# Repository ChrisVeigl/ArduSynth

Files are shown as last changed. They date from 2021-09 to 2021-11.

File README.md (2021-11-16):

# ArduSynth
HW/SW for low-cost Arduino-based audio synthesizers, using the Mozzi Library.
Currently, two designs are available: one for the Arduino Nano and one for the TeensyLC microcontroller. The TeensyLC version is recommended and will be updated in the future - it offers more features like Midi control via the Teensy's usbMidi functions.
The KICad projects (Schematics, PCB) are available in the respective HW folders, partnumbers @ digikey / Aliexpress are provided.

## About the demo Synth Sketches

Synthesizer sketches can be added / modified on demand. Currently there are two demo synth designs available, based upon:

* the "K'iin" Synthesizer by Taylan Cihan, see: http://digital.music.cornell.edu/taylancihan/kiin.html
 
* the "Thankyou Drone Synth" by Daniel Sinderson, see:
   https://create.arduino.cc/projecthub/scraptured/phasemod-drone-synth-w-arduino-nano-mozzi-7ab2ff 

## SW-Build instructions and Dependencies

* for compiling the software, the Mozzi-Library must be installed / copied to the Arduino libraries folder, see:
https://github.com/sensorium/Mozzi 

For the TeensyLC version, follwing alternative/additional libraries are used:
* currently this branch of the Mozzi library is needed for TeensyLC support: https://github.com/tomcombriat/Mozzi/tree/Teensy4X
* the Adafruit library for the SSD1306 OLed-Display is used: https://github.com/adafruit/Adafruit_SSD1306 
Please note that a modified version of this library is delivered in the src folder - the display method was adapted in order to call audioHook() - which prevents distorted audio during display updates.
* furthermore, the Adafruit GFX library https://github.com/adafruit/Adafruit-GFX-Library and the Adafruit BUI-IO library https://github.com/adafruit/Adafruit_BusIO are needed - they can be installed from the Arduinos Library manager.
* in order to use the correct I2C interface of the TeensyLC, the Wire1 interface must be enabled either by adding "-DWIRE_IMPLEMENT_WIRE1" to the teensyLC.build.flags.defs in the file Arduino\hardware\teensy\avr\boards.txt file or by uncommenting line 43 in file Arduino\hardware\teensy\avr\libraries\Wire\WireKinetis.h

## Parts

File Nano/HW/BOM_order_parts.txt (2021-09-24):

Arduino Nano: https://de.aliexpress.com/item/32824272738.html
Potentiomenter + Knobs: https://de.aliexpress.com/item/1005001346661310.html

other parts:
https://www.digikey.at/product-detail/de/w%C3%BCrth-elektronik/430476085716/430476085716-ND/5209048
https://www.digikey.at/product-detail/de/creeled-inc/C503B-BCS-CV0Z0461/C503B-BCS-CV0Z0461-ND/1922944
https://www.digikey.at/product-detail/de/stackpole-electronics-inc/CF14JT470R/CF14JT470RCT-ND/1830342
https://www.digikey.at/product-detail/de/harwin-inc/M20-9990345/952-2263-ND/3728227
https://www.digikey.at/product-detail/de/sullins-connector-solutions/NPC02SXON-RC/S9341-ND/2618266
https://www.digikey.at/product-detail/de/adam-tech/EB147A-02-D/2057-EB147A-02-D-ND/9830728
https://at.rs-online.com/web/p/klinken-steckerbuchsen/8051655

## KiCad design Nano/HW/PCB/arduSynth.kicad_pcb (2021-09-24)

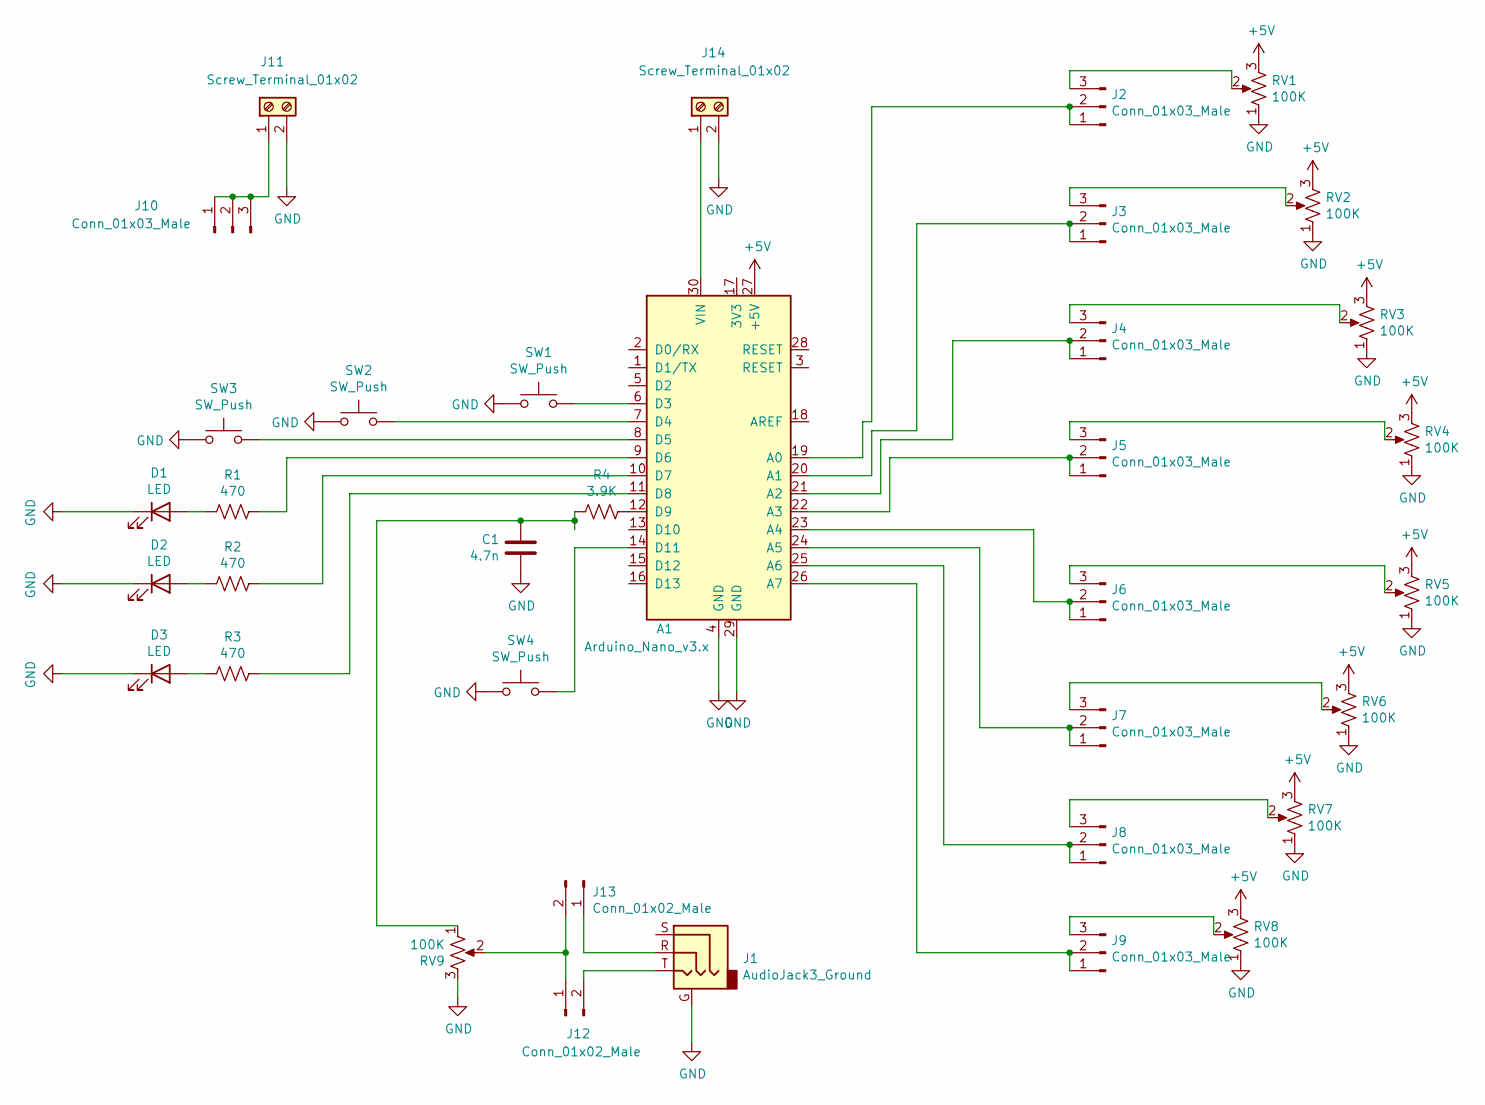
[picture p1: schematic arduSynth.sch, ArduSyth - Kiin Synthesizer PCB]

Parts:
A1: Arduino_Nano_v3.x; Arduino_Nano
C1: 4.7n; C_Rect_L4.6mm_W2.0mm_P2.50mm_MKS02_FKP02
D1, D2, D3: LED; LED_D5.0mm
J1: AudioJack3_Ground; FC68125
J2, J3, J4, J5, J6, J7, J8, J9, J10: Conn_01x03_Male; PinHeader_1x03_P2.54mm_Vertical
J11, J14: Screw_Terminal_01x02; TerminalBlock_bornier-2_P5.08mm
J12, J13: Conn_01x02_Male; PinHeader_1x02_P2.54mm_Vertical
R1, R2, R3: 470; R_Axial_DIN0204_L3.6mm_D1.6mm_P2.54mm_Vertical
R4: 3.9K; R_Axial_DIN0204_L3.6mm_D1.6mm_P2.54mm_Vertical
RV1, RV2, RV3, RV4, RV5, RV6, RV7, RV8, RV9: 100K; Potentiometer_Alps_RK09K_Single_Vertical_modified
SW1, SW2, SW3, SW4: SW_Push; SW_PUSH-12mm_Wuerth-430476085716

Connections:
+5V: A1.27 (+5V), RV1.3, RV2.3, RV3.3, RV4.3, RV5.3, RV6.3, RV7.3, RV8.3
GND: A1.4 (GND), A1.29 (GND), C1.2, D1.1 (K), D2.1 (K), D3.1 (K), J1.G, J11.2, J14.2, RV1.1, RV2.1, RV3.1, RV4.1, RV5.1, RV6.1, RV7.1, RV8.1, RV9.3, SW1.1, SW2.1, SW3.1, SW4.1
unnamed: A1.6 (D3), SW1.2
unnamed: A1.7 (D4), SW2.2
unnamed: A1.8 (D5), SW3.2
unnamed: A1.9 (D6), R1.2
unnamed: A1.10 (D7), R2.2
unnamed: A1.11 (D8), R3.2
unnamed: A1.12 (D9), R4.2
unnamed: A1.14 (D11), SW4.2
unnamed: A1.19 (A0), J2.1, J2.2
unnamed: A1.20 (A1), J3.1, J3.2
unnamed: A1.21 (A2), J4.1, J4.2
unnamed: A1.22 (A3), J5.1, J5.2
unnamed: A1.23 (A4), J6.1, J6.2
unnamed: A1.24 (A5), J7.1, J7.2
unnamed: A1.25 (A6), J8.1, J8.2
unnamed: A1.26 (A7), J9.1, J9.2
unnamed: A1.30 (VIN), J14.1
unnamed: C1.1, R4.1, RV9.1
unnamed: D1.2 (A), R1.1
unnamed: D2.2 (A), R2.1
unnamed: D3.2 (A), R3.1
unnamed: J1.R, J13.1
unnamed: J1.T, J12.2
unnamed: J2.3, RV1.2
unnamed: J3.3, RV2.2
unnamed: J4.3, RV3.2
unnamed: J5.3, RV4.2
unnamed: J6.3, RV5.2
unnamed: J7.3, RV6.2
unnamed: J8.3, RV7.2
unnamed: J9.3, RV8.2
unnamed: J10.1, J10.2, J10.3, J11.1
unnamed: J12.1, J13.2, RV9.2

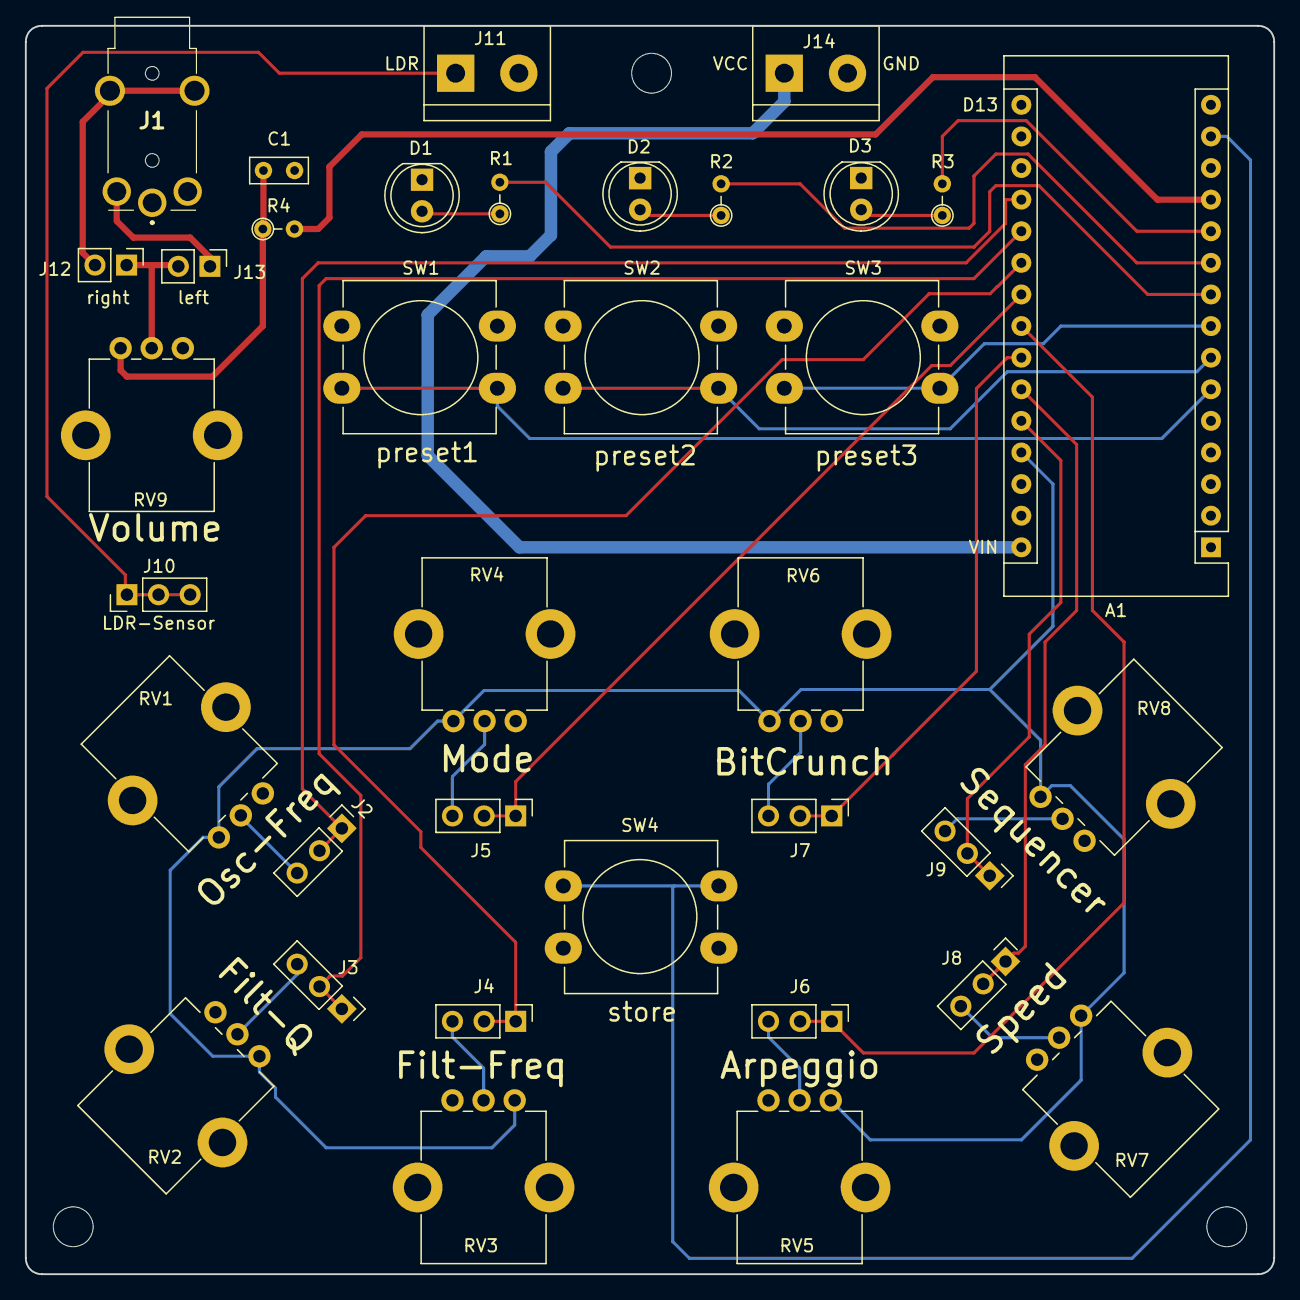
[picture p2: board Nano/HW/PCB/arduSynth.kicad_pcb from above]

Board: 2 copper layers, 100.3 x 100.3 mm, 36 parts (0 on the bottom side), 35 nets.

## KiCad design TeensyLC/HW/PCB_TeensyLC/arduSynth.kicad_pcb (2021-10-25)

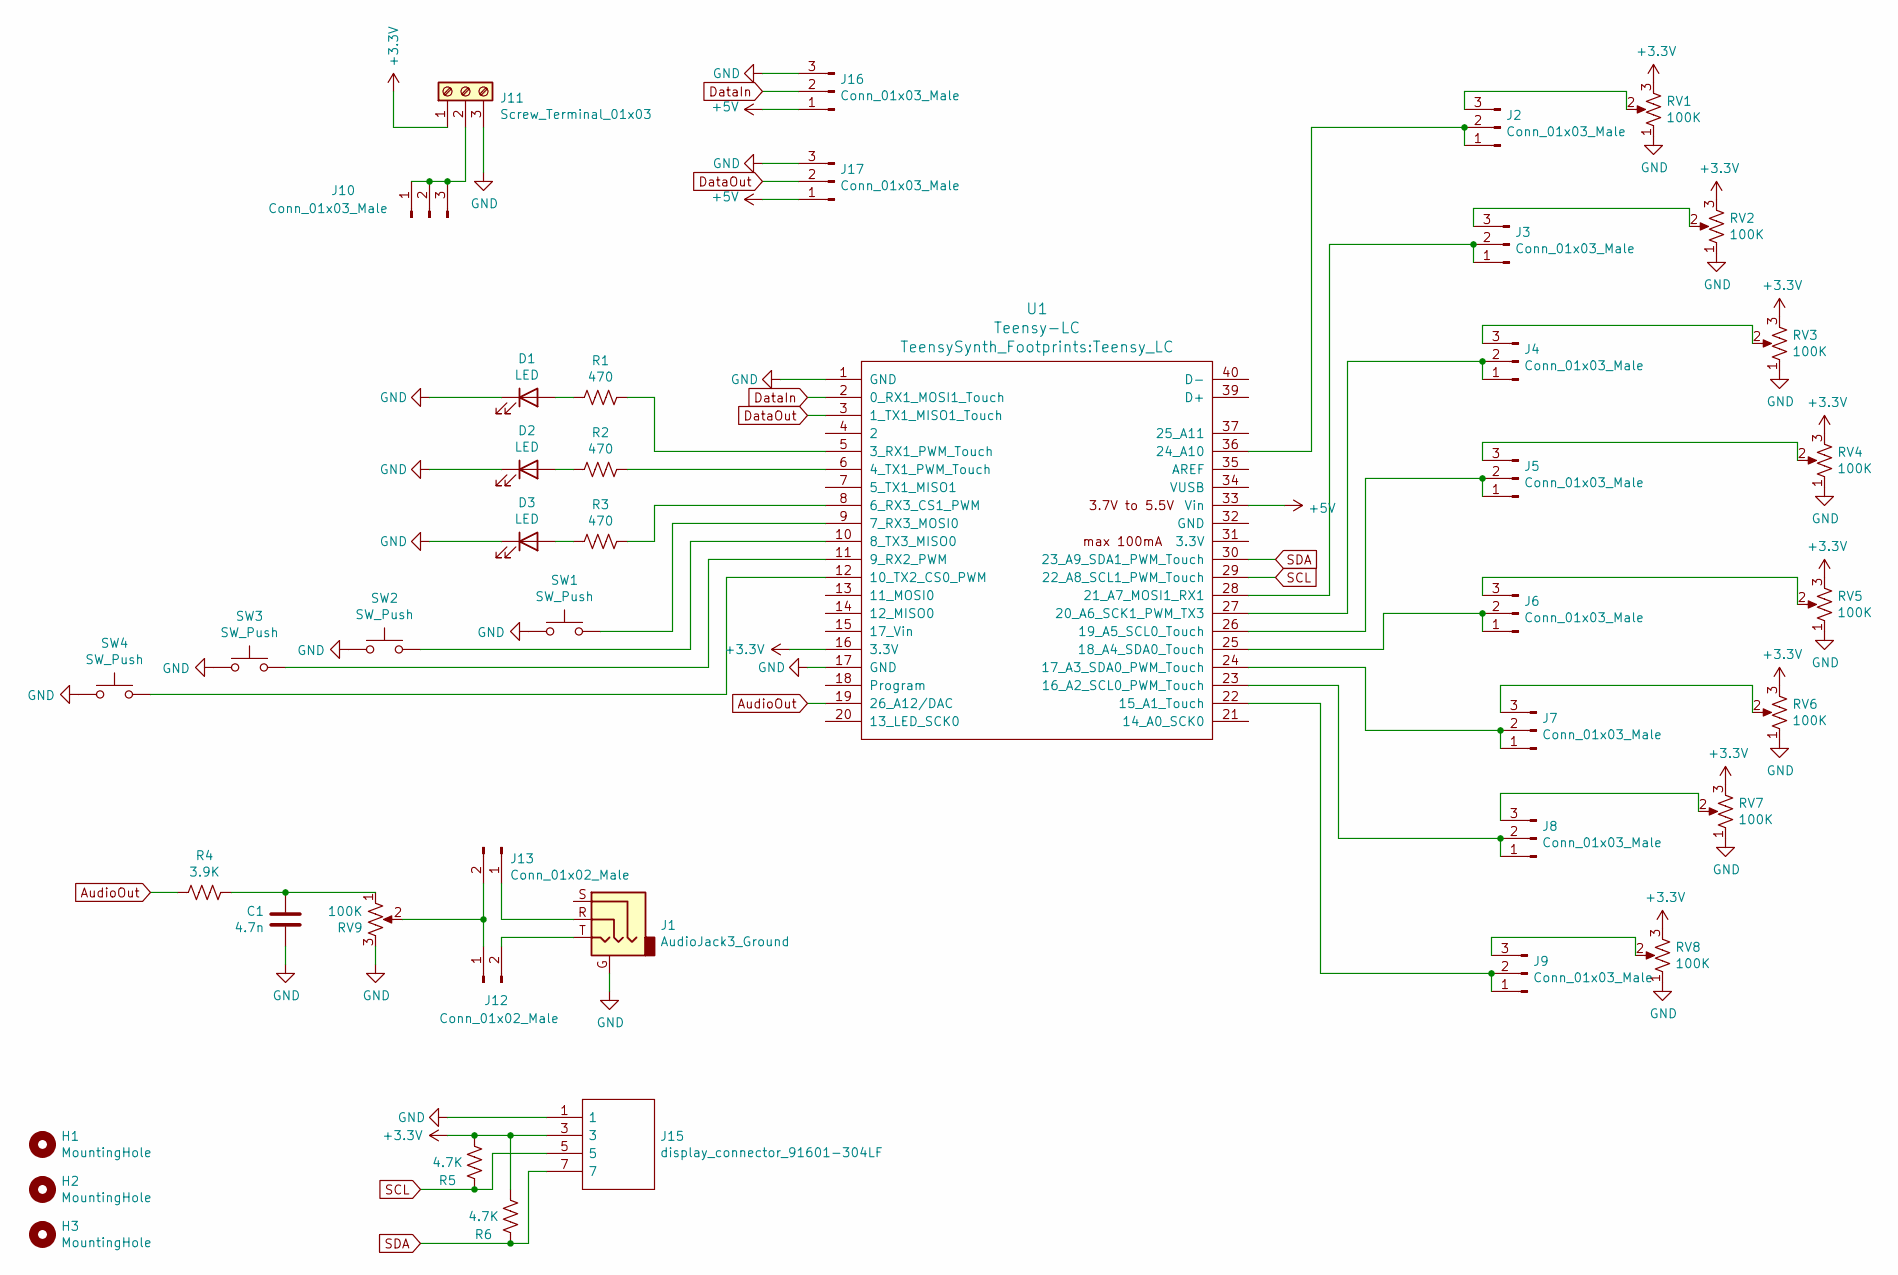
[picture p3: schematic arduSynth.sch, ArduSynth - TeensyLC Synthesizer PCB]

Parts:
C1: 4.7n; C_Rect_L4.6mm_W2.0mm_P2.50mm_MKS02_FKP02
D1, D2, D3: LED; LED_D5.0mm
H1, H2, H3: MountingHole; MountingHole_3.2mm_M3_Pad
J1: AudioJack3_Ground; FC68125
J2, J3, J4, J5, J6, J7, J8, J9, J10, J16, J17: Conn_01x03_Male; PinHeader_1x03_P2.54mm_Vertical
J11: Screw_Terminal_01x03; TerminalBlock_bornier-3_P5.08mm
J12, J13: Conn_01x02_Male; PinHeader_1x02_P2.54mm_Vertical
J15: display_connector_91601-304LF; 91601304LF; Mouser Part Number 649-91601-304LF
R1, R2, R3: 470; R_Axial_DIN0204_L3.6mm_D1.6mm_P2.54mm_Vertical
R4: 3.9K; R_Axial_DIN0204_L3.6mm_D1.6mm_P2.54mm_Vertical
R5, R6: 4.7K; R_Axial_DIN0204_L3.6mm_D1.6mm_P2.54mm_Vertical
RV1, RV2, RV3, RV4, RV5, RV6, RV7, RV8, RV9: 100K; Potentiometer_Alps_RK09K_Single_Vertical_modified
SW1, SW2, SW3, SW4: SW_Push; SW_PUSH-12mm_Wuerth-430476085716
U1: Teensy-LC; Teensy_LC

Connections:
+3V3: J11.1, J15.3, R5.1, R6.1, RV1.3, RV2.3, RV3.3, RV4.3, RV5.3, RV6.3, RV7.3, RV8.3, U1.16 (3.3V)
+5V: J16.1, J17.1, U1.33 (Vin)
AudioOut: R4.1, U1.19 (26_A12/DAC)
DataIn: J16.2, U1.2 (0_RX1_MOSI1_Touch)
DataOut: J17.2, U1.3 (1_TX1_MISO1_Touch)
GND: C1.2, D1.1 (K), D2.1 (K), D3.1 (K), J1.G, J11.3, J15.1, J16.3, J17.3, RV1.1, RV2.1, RV3.1, RV4.1, RV5.1, RV6.1, RV7.1, RV8.1, RV9.3, SW1.1, SW2.1, SW3.1, SW4.1, U1.1 (GND), U1.17 (GND)
unnamed: C1.1, R4.2, RV9.1
unnamed: D1.2 (A), R1.1
unnamed: D2.2 (A), R2.1
unnamed: D3.2 (A), R3.1
unnamed: J1.R, J13.1
unnamed: J1.T, J12.2
unnamed: J2.1, J2.2, U1.36 (24_A10)
unnamed: J2.3, RV1.2
unnamed: J3.1, J3.2, U1.28 (21_A7_MOSI1_RX1)
unnamed: J3.3, RV2.2
unnamed: J4.1, J4.2, U1.27 (20_A6_SCK1_PWM_TX3)
unnamed: J4.3, RV3.2
unnamed: J5.1, J5.2, U1.26 (19_A5_SCL0_Touch)
unnamed: J5.3, RV4.2
unnamed: J6.1, J6.2, U1.25 (18_A4_SDA0_Touch)
unnamed: J6.3, RV5.2
unnamed: J7.1, J7.2, U1.24 (17_A3_SDA0_PWM_Touch)
unnamed: J7.3, RV6.2
unnamed: J8.1, J8.2, U1.23 (16_A2_SCL0_PWM_Touch)
unnamed: J8.3, RV7.2
unnamed: J9.1, J9.2, U1.22 (15_A1_Touch)
unnamed: J9.3, RV8.2
unnamed: J10.1, J10.2, J10.3, J11.2
unnamed: J12.1, J13.2, RV9.2
unnamed: R1.2, U1.5 (3_RX1_PWM_Touch)
unnamed: R2.2, U1.6 (4_TX1_PWM_Touch)
unnamed: R3.2, U1.8 (6_RX3_CS1_PWM)
unnamed: SW1.2, U1.9 (7_RX3_MOSI0)
unnamed: SW2.2, U1.10 (8_TX3_MISO0)
unnamed: SW3.2, U1.11 (9_RX2_PWM)
unnamed: SW4.2, U1.12 (10_TX2_CS0_PWM)
SCL: J15.5, R5.2, U1.29 (22_A8_SCL1_PWM_Touch)
SDA: J15.7, R6.2, U1.30 (23_A9_SDA1_PWM_Touch)

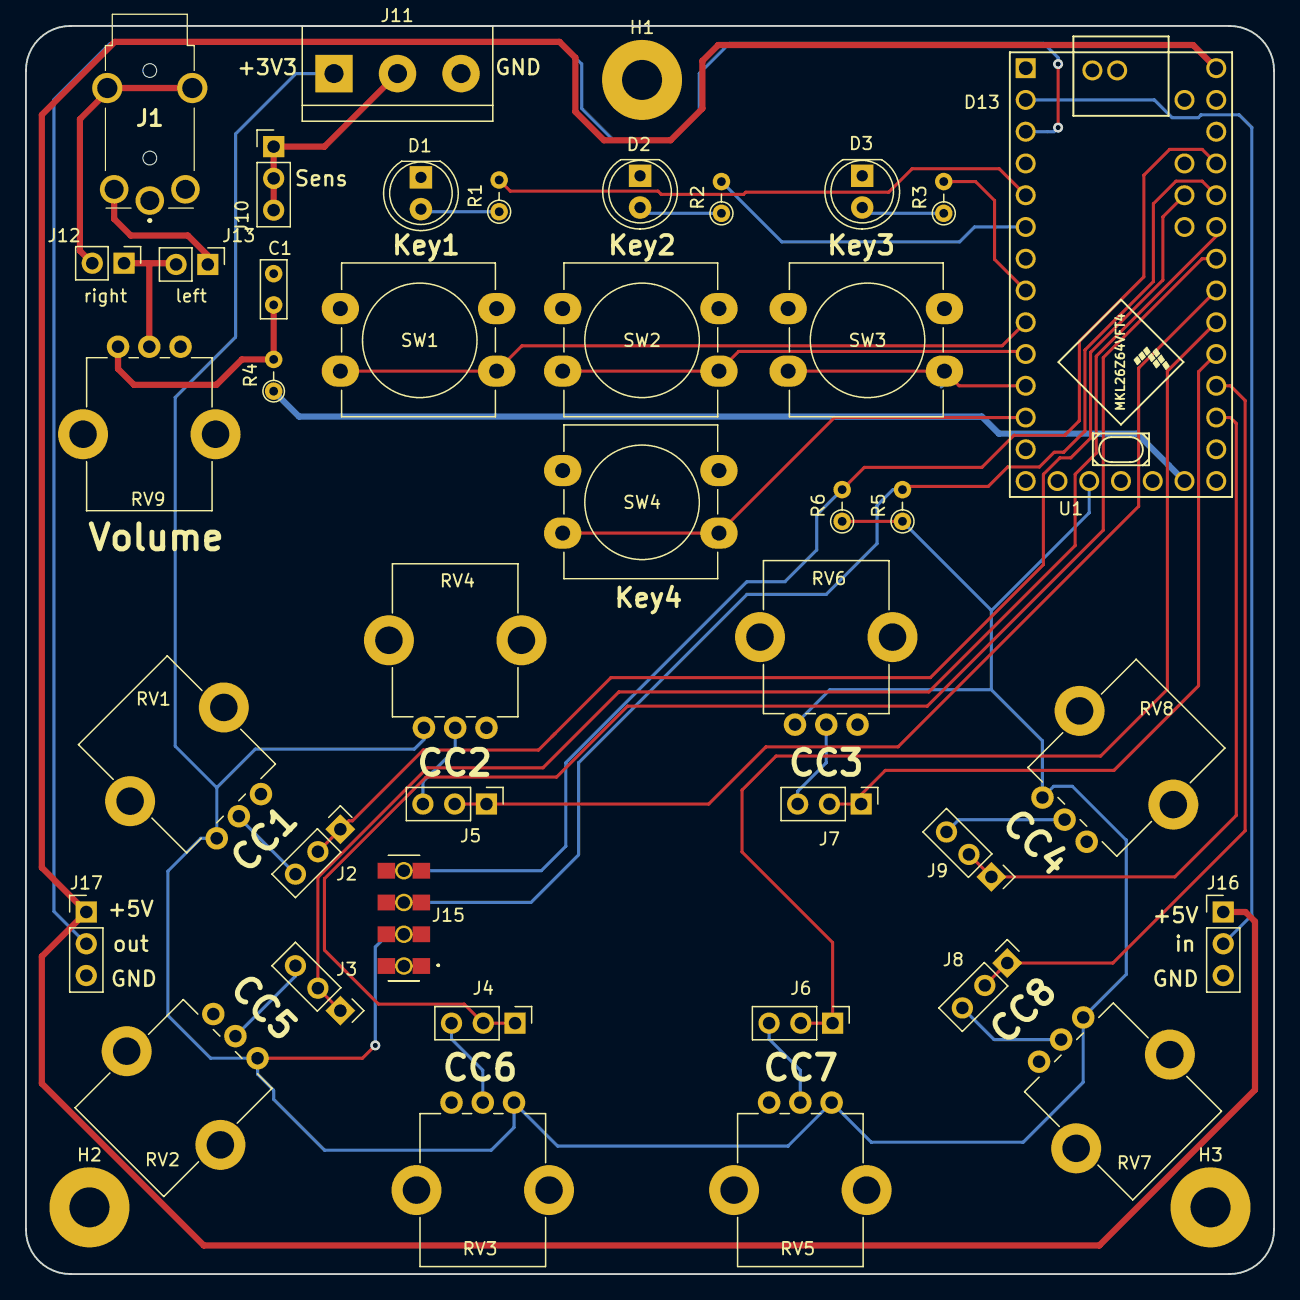
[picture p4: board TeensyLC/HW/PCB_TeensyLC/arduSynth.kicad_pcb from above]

Board: 2 copper layers, 99.8 x 99.8 mm, 43 parts (0 on the bottom side), 39 nets.

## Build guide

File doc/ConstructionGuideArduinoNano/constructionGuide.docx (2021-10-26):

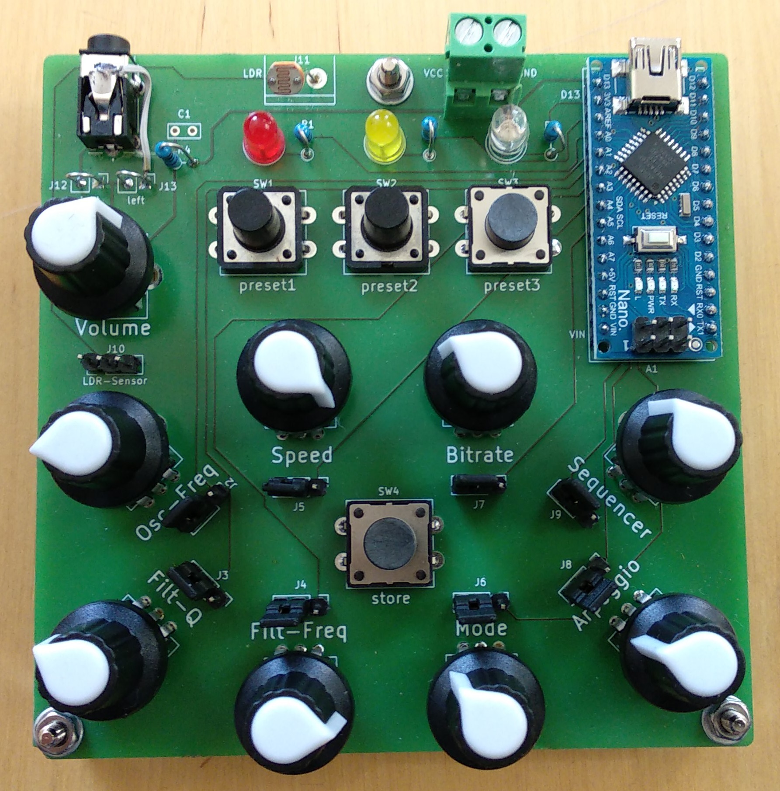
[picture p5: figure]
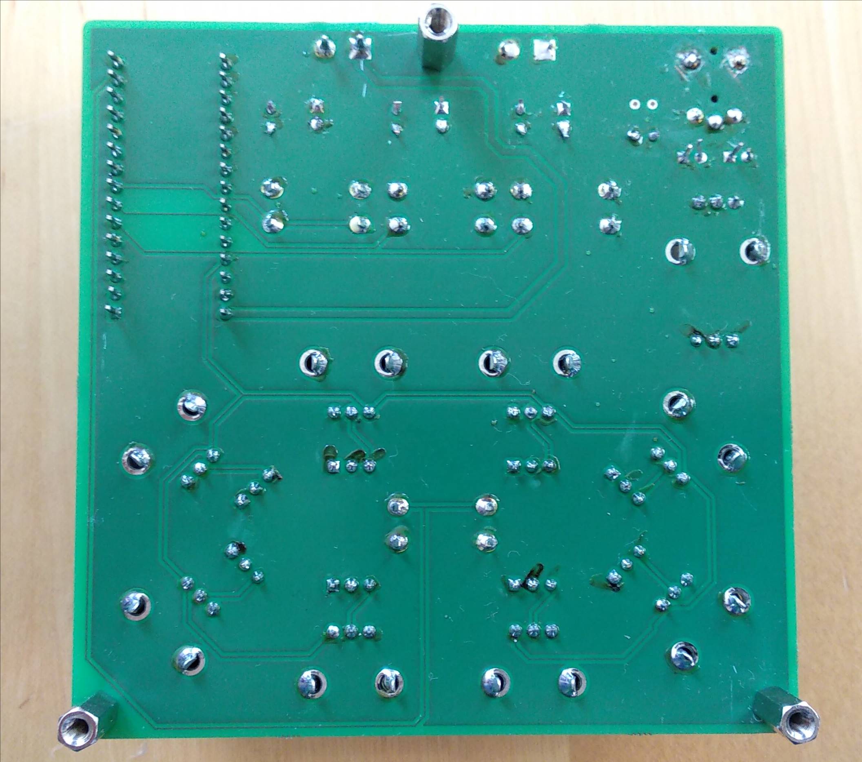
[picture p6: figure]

+

+

+

Rückseite, Lötseite (back, soldering side) Arduino Synthesizer, Vorderseite (front)

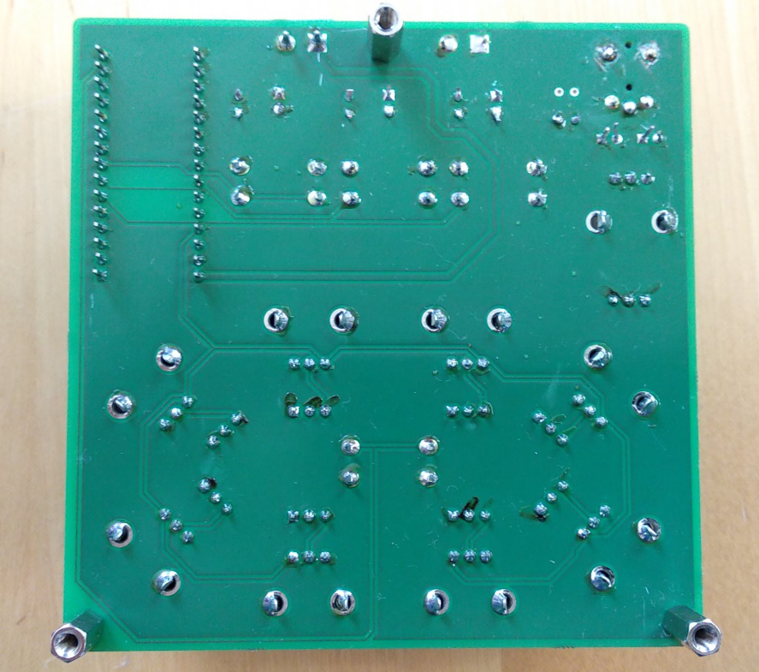
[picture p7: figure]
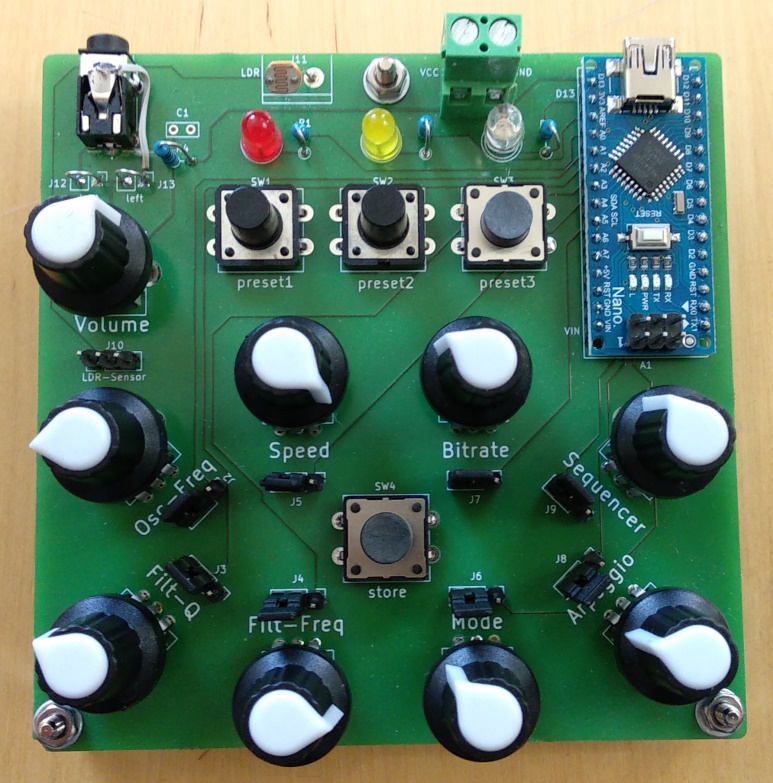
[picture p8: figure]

+

+

+

Rückseite, Lötseite (back, soldering side) Arduino Synthesizer, Vorderseite (front)

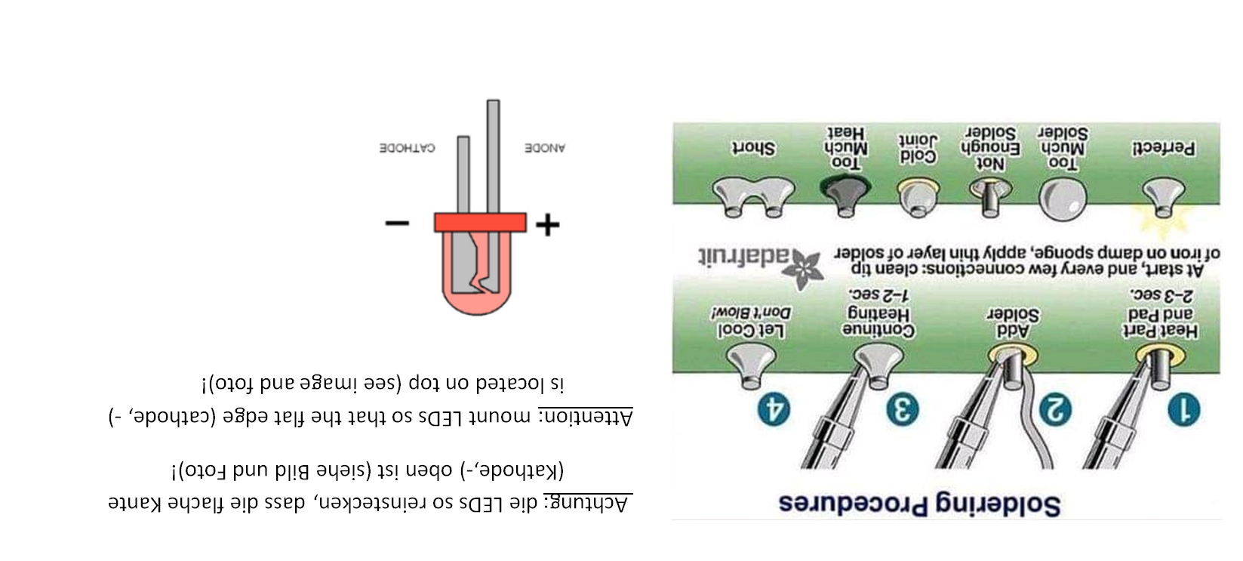
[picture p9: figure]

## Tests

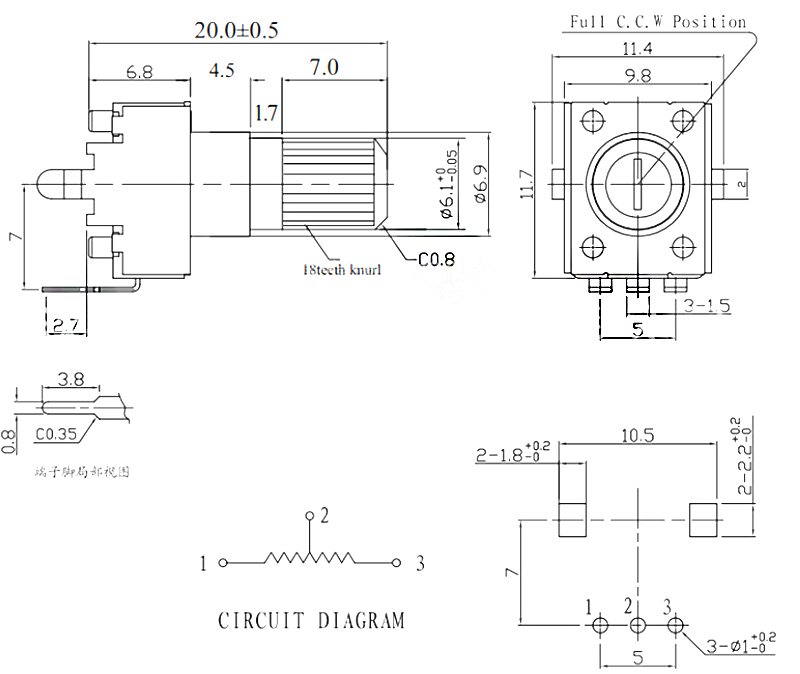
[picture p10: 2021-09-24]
doc/components&datasheets/poti_footprint_measures.jpg

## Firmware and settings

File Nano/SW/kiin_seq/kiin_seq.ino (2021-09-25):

//
// based upon K'iin Synthesizer by Taylan Cihan
// http://digital.music.cornell.edu/taylancihan/kiin.html
//
// modified for FuzzyK'iin PCB by Chris Veigl
//


// 
// ---- INITIALS ----
//


#include <MozziGuts.h>
#include <WavePacket.h>
#include <RollingAverage.h>
#include <AutoMap.h>
#include <EventDelay.h>
#include <mozzi_rand.h>
#include <EEPROM.h>

// #define PCB_V1 

#define DEBUG_OUTPUT 1
#define CONTROL_RATE 64

WavePacket <DOUBLE> wavey; // DOUBLE selects 2 overlapping streams
EventDelay kEventDelay;
int bitR = 8;
int krModSpd = 2;
int counter = 0;



// 
// ---- ANALOG INPUTS ----
//

#ifdef PCB_V1
const int KNOB1_PIN = 0; // oscillator freq
const int KNOB2_PIN = 1; // filter q
const int KNOB3_PIN = 2; // filter freq
const int KNOB5_PIN = 3; // playback mode
const int KNOB7_PIN = 4; // arpeggio
const int KNOB6_PIN = 5; // bit rate
const int KNOB4_PIN = 6; // control speed
const int KNOB8_PIN = 7; // sequencer speed
#else
const int KNOB1_PIN = 0; // oscillator freq
const int KNOB2_PIN = 1; // filter q
const int KNOB3_PIN = 2; // filter freq
const int KNOB4_PIN = 3; // control speed
const int KNOB5_PIN = 4; // playback mode
const int KNOB6_PIN = 5; // bit rate
const int KNOB7_PIN = 6; // arpeggio speed
const int KNOB8_PIN = 7; // sequencer speed

#endif


// 
// ---- AUTOMAPS ----
//
AutoMap kMapF(0, 1023, 5, 100); // oscillator freq (knob 1)
AutoMap kMapFT(5, 100, 0, 12); // oscillator tuning-array index (knob 1)
AutoMap kMapTuneArrSel(4, 64, 0, 5); // oscillator tuning-array index (knob 4)
AutoMap kMapBw(0, 1023, 1, 1000); // filter q (knob 2)
AutoMap kMapCf(0, 1023, 60, 2000); // filter freq (knob 3)
AutoMap kMapArrL(0, 1023, 4, 64); // control speed for random from array (mode3&4, knob 4)
AutoMap kMapMode(0, 1023, 0, 5); // mode (knob 5)
AutoMap kMapBit(0, 1023, 1, 7); // bit rate (knob 6)
AutoMap kMapModSpd(0, 1023, 1, 40); // modulation speed (knob 7)
AutoMap kMapModArrL(4, 64, 4, 40); // modulation array length (knob 4)



// 
// ---- ARRAYS ----
//
int arr[] = { 2, 2, 1, 1, 1, 1, 1, 1, 1, 1, 1, 1, 1, 1, 1, 1, 1, 1, 1, 2, 1, 1, 1, 1, 1, 1, 1, 1, 1, 1, 1, 1,
1, 1, 1, 2, 1, 1, 1, 1, 1, 1, 1, 1, 1, 1, 1, 1, 1, 1, 1, 2, 1, 1, 1, 1, 1, 1, 1, 1, 1, 1, 1, 1 };
float tuneArr[6][13] = {
  { 1, 1.285, 1.5, 1.75, 2, 2.25, 2.57, 2.8, 3, 3.11, 3.5, 3.857, 4 }, // overtone series
  { 1, 1.166, 1.33, 1.5, 1.75, 2, 2.332, 2.66, 3.0, 3.5, 4, 4.664, 6 }, // pentatonic
  { 1, 1.166, 1.5, 2, 2.33, 3.0, 4, 4.66, 6.0, 8, 9.33, 12, 16 }, // minor arpeggio
  { 1, 1.25, 1.5, 2, 2.5, 3.0, 4, 5.0, 6.0, 8, 10, 12, 16 }, // major arpeggio
  { 1, 1.25, 1.56, 2, 2.5, 3.12, 4, 5.0, 6.24, 8, 10, 12.48, 16 }, // augmented arpeggio
  { 1, 1.071, 1.25, 1.33, 1.5, 1.56, 1.890, 2.0, 2.142, 2.5, 2.66, 3.0, 3.12 } // hicaz
};
int stepModArr[] = { 25, 50, 75, 100, 150, 200, 300, 400, 800, 1600, 2400, 3000, 2400, 1200, 800, 400, 300, 150, 75, 50 };

#define KNOBS 7
#define SEQ_STEPS 3

#define BUTTON_REC 11
#define BUTTONS_STEP 3
#define LEDS_STEP 6

#define MIN_POTI_MOVEMENT 5
#define POTI_LIVE_VALUE 1025

#define STORE_BYPASS_TIME  64
#define SELECT_BYPASS_TIME 10

#define MAGIC_BYTE 123

uint16_t storedPositions[SEQ_STEPS][KNOBS]={512};
uint16_t actPosition[KNOBS];
uint16_t holdPosition[KNOBS]={POTI_LIVE_VALUE};
uint8_t  actStep=0;
uint8_t  storing=0;
uint16_t bypass_button=0;
uint16_t seq_counter=0;
uint16_t  initParameters=10;


// 
// ---- SETUP ----
//
void setup() {
  Serial.begin(115200);
  Serial.println ("  ********* Welcome to Kiin Synth/ Sequencer  *************");
  randSeed();

  pinMode (BUTTON_REC, INPUT_PULLUP);
  pinMode (BUTTONS_STEP, INPUT_PULLUP);
  pinMode (BUTTONS_STEP+1, INPUT_PULLUP);
  pinMode (BUTTONS_STEP+2, INPUT_PULLUP);

  pinMode (LEDS_STEP, OUTPUT);
  pinMode (LEDS_STEP+1, OUTPUT);
  pinMode (LEDS_STEP+2, OUTPUT);

  if (EEPROM.read (0) == MAGIC_BYTE)  {
     EEPROM.get (1,storedPositions);
    // EEPROM.get (50,wavey);
  }

  memcpy (actPosition,storedPositions[actStep],sizeof(actPosition));
  
  delay(200);
  startMozzi(CONTROL_RATE);
  for (uint8_t z=0;z<KNOBS;z++) holdPosition[z]=1024-mozziAnalogRead(z);  // hold current poti positions!      

}


void getSequence(uint8_t seq) {
    digitalWrite (actStep+LEDS_STEP,LOW);
    actStep=seq;
    digitalWrite(actStep+LEDS_STEP,HIGH);
    memcpy (actPosition,storedPositions[actStep],sizeof(actPosition));
    for (uint8_t z=0;z<KNOBS;z++) holdPosition[z]=1024-mozziAnalogRead(z);  // hold current poti positions!      
    if (DEBUG_OUTPUT) {
      Serial.print ("RECALLING STEP "); Serial.println (actStep);
      for (int i=0; i<KNOBS; i++) {
        Serial.print ("Knob "); Serial.print (i+1); Serial.print (": "); Serial.print (actPosition[i]); 
        Serial.print (" - Poti locked at "); Serial.println (holdPosition[i]); 
      }      
    }
}




// 
// ---- CONTROL ----
//
void updateControl() { 

  if (initParameters) {
    for (int i=0;i<KNOBS;i++) {
      actPosition[i]=rand(1023); 
    }
    initParameters--;
    if (initParameters == 0) getSequence(0);
  }

  if (( digitalRead (BUTTON_REC) == LOW) && (!storing)) {  // rec pressed: store parameters of current sequence slot
    storing = STORE_BYPASS_TIME;
    memcpy (storedPositions[actStep],actPosition,sizeof(actPosition));
    EEPROM.update (0,MAGIC_BYTE);
    EEPROM.put (1,storedPositions);
  //  EEPROM.put (50,wavey);

    if (DEBUG_OUTPUT) {
      Serial.print ("STORING STEP "); Serial.println (actStep);
      for (int i=0; i<KNOBS; i++) {
        Serial.print ("Knob "); Serial.print (i+1); Serial.print (": "); Serial.println (storedPositions[actStep][i]); 
      }
    }
  }

  if (storing) {  // blink led of current sequence slot when storing 
    if (storing & 8) digitalWrite (actStep+LEDS_STEP,HIGH); else digitalWrite (actStep+LEDS_STEP,LOW);
    if (!(--storing)) digitalWrite (actStep+LEDS_STEP,HIGH);
  }

  uint16_t seq_speed =1024-mozziAnalogRead(KNOB8_PIN);  // sequencing speed 
  if (seq_speed > 10) {
    seq_speed-=10;
    seq_counter++;
    if (seq_counter > 130-(seq_speed >> 3)) {
      seq_counter=0;
      getSequence((actStep+1) % SEQ_STEPS);  // perform automatic slot change
    }
  }

  for (uint8_t i=0;i<SEQ_STEPS; i++) {
    if ((digitalRead (BUTTONS_STEP+i) == LOW) && (!bypass_button)) {  // step button was pressed: manual slot change
      bypass_button=SELECT_BYPASS_TIME;
      getSequence(i);
    }
  }

  if (bypass_button) bypass_button--;
  
  for (uint8_t i=0;i<KNOBS;i++) {
    uint16_t currentPotiValue=1024-mozziAnalogRead(i);

    if (!initParameters) {
      if (holdPosition[i]==POTI_LIVE_VALUE) {
        actPosition[i]=currentPotiValue;
      } 
      else {  // use stored parameter position!
        int delta=holdPosition[i]-currentPotiValue;
        if (( delta > MIN_POTI_MOVEMENT ) || (delta < -MIN_POTI_MOVEMENT)) {
          holdPosition[i]=POTI_LIVE_VALUE;  // allow LIVE_VALUES if poti was moved!
          if (DEBUG_OUTPUT) {
            Serial.print ("unlock Knob "); Serial.print (i+1); Serial.print (" delta="); Serial.println (delta);
          }
        }
      }
    } 
    //else initParameters=0; 
  }
  
  // mod Spd
  krModSpd = actPosition[KNOB7_PIN];
  krModSpd = kMapModSpd(krModSpd);
  kEventDelay.set(krModSpd);
  
  // bit rate
  bitR = actPosition[KNOB6_PIN];
  bitR = kMapBit(bitR);
  
  // mode
  int mode = actPosition[KNOB5_PIN];
  mode = kMapMode(mode);
  
  // array length
  int arrMax = actPosition[KNOB4_PIN];
  arrMax = kMapArrL(arrMax);
  
  // synth properties
  float fundamental = actPosition[KNOB1_PIN]+1;
  float bandwidth = actPosition[KNOB2_PIN];
  float centre_freq = actPosition[KNOB3_PIN];
  
  
  // OPERATION  
  // knob values
  if (mode == 0) 
  {
    fundamental = kMapF(fundamental);
    bandwidth = kMapBw(bandwidth);
    centre_freq = kMapCf(centre_freq);
    wavey.set(fundamental, bandwidth, centre_freq);
  }
  
  
  // scales
  else if (mode == 1)
  {
    int tuneArrSel;
    int tunArrI;
    tuneArrSel = kMapTuneArrSel(arrMax); // select which array for tuning
    fundamental = kMapF(fundamental); // map fundamental
    tunArrI = kMapFT(fundamental); // tuning array index
    fundamental = tuneArr[tuneArrSel][tunArrI] * 44; // tune fundamental
    bandwidth = kMapBw(bandwidth);
    centre_freq = kMapCf(centre_freq);
    wavey.set(fundamental, bandwidth, centre_freq);
  }
  
  
  // randomize fundamental frequency from array
  else if (mode == 2)
  {
    if (arr[rand(arrMax)] == 2)
    {
      int randFreq = rand(5, 100);
      fundamental = kMapF(fundamental);
      fundamental = fundamental + randFreq;
    }
    bandwidth = kMapBw(bandwidth);
    centre_freq = kMapCf(centre_freq); 
    wavey.set(fundamental, bandwidth, centre_freq);
  }
  
  
  // randomize all values from array
  else if (mode == 3)
  {
    int f = arr[rand(arrMax)]; // frequency
    int b = arr[rand(arrMax)]; // bandwidth
    int c = arr[rand(arrMax)]; // center freq
    if (f == 2)
    {
      int rFq = rand(5, 100);
      fundamental = kMapF(fundamental);
      fundamental = fundamental + rFq;
    }
    if (b == 2)
    {
      int rBW = rand(100, 1000);
      bandwidth = kMapBw(bandwidth);
      bandwidth = bandwidth + rBW;
    }
    if (c == 2)
    {
      int rCF = rand(1000, 2500); 
      centre_freq = kMapCf(centre_freq); 
      centre_freq = centre_freq + rCF;
    } 
    wavey.set(fundamental, bandwidth, centre_freq);
  }
  
  
  // randomize all values
  else if (mode == 4)
  {
    int rF = arrMax + 1; // how much random
    fundamental = kMapF(fundamental);
    bandwidth = kMapBw(bandwidth);
    centre_freq = kMapCf(centre_freq); 
    fundamental = fundamental + rand(rF*3);
    bandwidth = bandwidth + rand(rF*25);
    centre_freq = centre_freq + rand(rF*10, rF*40);
    wavey.set(fundamental, bandwidth, centre_freq);
  }
  
  
  // arpeggio
  else if (mode == 5)
  {
    if (kEventDelay.ready()) 
    {
      int stepModLenth = kMapModArrL(arrMax);
      counter++;
      if (counter >= stepModLenth) { counter = 0; }    
      kEventDelay.start();
      fundamental = fundamental + stepModArr[counter];
      bandwidth = kMapBw(bandwidth);
      centre_freq = kMapCf(centre_freq);
      wavey.set(fundamental, bandwidth, centre_freq);
      if (DEBUG_OUTPUT) Serial.println(counter);
    }
  }  
  
}



// 
// ---- AUDIO ----
//
int updateAudio() {
  return wavey.next()>>bitR;
}



// 
// ---- LOOP ----
//
void loop() {
  audioHook(); // required here
}

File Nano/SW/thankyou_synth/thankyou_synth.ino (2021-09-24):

/*
 
   Based upon "Thankyou Synth" - by Daniel Sinderson 
   https://create.arduino.cc/projecthub/scraptured/phasemod-drone-synth-w-arduino-nano-mozzi-7ab2ff

   modified for FuzzyK'iin V1 PCB by Chris Veigl
 
 */

#include <MozziGuts.h>
#include <Oscil.h>
#include <Smooth.h>
#include <AutoMap.h>
#include <Ead.h> // exponential attack decay
#include <mozzi_rand.h>

#include <tables/sin256_int8.h>
#include <tables/halfsin256_uint8.h>
#include <tables/waveshape1_softclip_int8.h>
#include <tables/saw256_int8.h>

#define CONTROL_RATE 256

// VARIABLES
AutoMap kMapCarrierFreq(0,1023,20,440);
AutoMap kMapIntensity(0,1023,700,1);
AutoMap kMapModSpeed(0,1023,10000,0);
AutoMap kMapEnvelopeTimes(0, 1023, 0, 1000);

Oscil <256, AUDIO_RATE> carrier;
Oscil <256, AUDIO_RATE> modulator;
Oscil <256, CONTROL_RATE> modDepth;

Ead kEnvelope(CONTROL_RATE); // resolution will be CONTROL_RATE

int actMode=0;
int attack = 20;
int decay = 20;
bool mode = 0;
bool noteTrigger1 = 0;
bool noteTrigger2 = 0;
bool noteTrigger3 = 0;

int  gain=0;
int freqs[3];
byte wfs[3];

int mod_ratio = 1; //frequency of the modulator as an integer multiple of the carrier
long fm_intensity; // carries control info from updateControl to updateAudio

float smoothness = 0.95f;
Smooth <long> aSmoothIntensity(smoothness);


// FUNCTIONS
void setWavetables() {
  if (wfs[0]==0) {carrier.setTable(SIN256_DATA);}
  else if (wfs[0]==1) {carrier.setTable(HALFSIN256_DATA);}
  else if (wfs[0]==2) {carrier.setTable(SAW256_DATA);}
  else if (wfs[0]==3) {carrier.setTable(WAVESHAPE1_SOFTCLIP_DATA);}

  if (wfs[1]==0) {modulator.setTable(SIN256_DATA);}
  else if (wfs[1]==1) {modulator.setTable(HALFSIN256_DATA);}
  else if (wfs[1]==2) {modulator.setTable(SAW256_DATA);}
  else if (wfs[1]==3) {modulator.setTable(WAVESHAPE1_SOFTCLIP_DATA);}

  if (wfs[2]==0) {modDepth.setTable(SIN256_DATA);}
  else if (wfs[2]==1) {modDepth.setTable(HALFSIN256_DATA);}
  else if (wfs[2]==2) {modDepth.setTable(SAW256_DATA);}
  else if (wfs[2]==3) {modDepth.setTable(WAVESHAPE1_SOFTCLIP_DATA);}
}

void readPins() {
  freqs[0] = 1024-mozziAnalogRead(A0);
  freqs[1] = mozziAnalogRead(A1);
  freqs[2] = mozziAnalogRead(A2);
  
  wfs[0] = mozziAnalogRead(A3) >> 8;
  wfs[1] = mozziAnalogRead(A4) >> 8;
  wfs[2] = mozziAnalogRead(A5) >> 8;

  mod_ratio = (mozziAnalogRead(A6) >> 7) + 1;
  decay = 5000- ( mozziAnalogRead(A7) << 2);
  Serial.println(decay);

  mode = digitalRead(11);
  noteTrigger1 = digitalRead(3);
  noteTrigger2 = digitalRead(4);
  noteTrigger3 = digitalRead(5);
}

void setFrequencies() {
    int carrier_freq = kMapCarrierFreq(freqs[0]);
    if (actMode) carrier_freq*=actMode;
    int mod_freq = carrier_freq * mod_ratio;

    int intensity_calibrated = kMapIntensity(freqs[2]);
    fm_intensity = ((long)intensity_calibrated * (modDepth.next()+128))>>8;

    float mod_speed = (float)kMapModSpeed(freqs[1])/1000;

    carrier.setFreq(carrier_freq);
    modulator.setFreq(mod_freq);
    modDepth.setFreq(mod_speed);    
}


// ################### THE GOODS! #####################

void setup() {
  Serial.begin(115200);
  Serial.print("Control Rate = ");  Serial.println(CONTROL_RATE);

  pinMode(3, INPUT_PULLUP);
  pinMode(4, INPUT_PULLUP);
  pinMode(5, INPUT_PULLUP);
  pinMode(11, INPUT_PULLUP);

  pinMode(6, OUTPUT);
  pinMode(7, OUTPUT);
  pinMode(8, OUTPUT);

  randSeed(); // fresh random, MUST be called before startMozzi - wierd bug
  startMozzi(CONTROL_RATE);
}


void updateControl() {
  static uint8_t noteTrigger1_old=1;
  static uint8_t noteTrigger2_old=1;
  static uint8_t noteTrigger3_old=1;
  static uint8_t mode_old=1;
  
  readPins();
  setWavetables();
  setFrequencies();

  if ((noteTrigger1 == 0) && (noteTrigger1_old == 1)) { 
       kEnvelope.start(decay >> 6,decay);
       digitalWrite(6,HIGH);  
       actMode=1;
  }
  if ((noteTrigger2 == 0) && (noteTrigger2_old == 1)) { 
       kEnvelope.start(decay >> 4,decay >> 1);
       digitalWrite(7,HIGH);  
       actMode=2;
  }
  if ((noteTrigger3 == 0) && (noteTrigger3_old == 1)) { 
       kEnvelope.start(decay >> 8,decay >> 1);
       digitalWrite(8,HIGH);  
       actMode=3;
  }
       
  if ((mode != mode_old) && ( mode == 0 )) { actMode=0; Serial.println("continous mode!");  }

  noteTrigger1_old=noteTrigger1;
  noteTrigger2_old=noteTrigger2;
  noteTrigger3_old=noteTrigger3;
  mode_old=mode;

  gain = (int) kEnvelope.next(); 
  if (gain==0) {       digitalWrite(6,LOW);   digitalWrite(7,LOW);   digitalWrite(8,LOW); }

  
}


int updateAudio() {
  long audio;

  long mod = aSmoothIntensity.next(fm_intensity) * modulator.next();
  if (actMode == 0) {
    audio = carrier.phMod(mod);
  }
  else {
    //Serial.println(gain);
    audio = (((long)carrier.phMod(mod) * gain)>>8);
  }
//  return audio << 6; // 14-bit number for HI-FI mode
  return audio; 
}

void loop() {
  audioHook();
}

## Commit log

2021-09-24 added V1.0
    [arduSynth.kicad_pcb, arduSynth.sch]
2021-09-25 updated poti positions for PCB version 1.0
2021-10-13 added teensy 3.x SW version
2021-10-16 improved Teensy LC sketch, added MIDI support
2021-10-17 added PCB version for TeensyLC
    [arduSynth.kicad_pcb, arduSynth.sch]
2021-10-24 updates for TeensyLC Version
    [arduSynth.kicad_pcb, arduSynth.sch]
2021-10-25 some final PCB updates for Teensynth V1.0
    [arduSynth.kicad_pcb, arduSynth.sch]
2021-10-26 updated directory stucture to reflect both HW versions
    [arduSynth.kicad_pcb, arduSynth.sch]
2021-10-26 removed obsolete files to reflect both HW versions
    [arduSynth.kicad_pcb, arduSynth.sch]
2021-10-26 use traditional analogRead because of mozziAnalogRead problems on TeensyLC
    [thankyou_synth_teensy.ino]
2021-10-30 added frequency table and correct carrier frequency for midi note on
    [thankyou_synth_teensy.ino]
2021-11-14 updates for TeensyLC and I2C-LCD
2021-11-16 added modified version of Adafruit SSD1306 library - preventing audio distortion during display updates
    [thankyou_synth_teensy.ino]
